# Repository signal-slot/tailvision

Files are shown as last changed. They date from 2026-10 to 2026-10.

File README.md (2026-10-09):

# tailvision

Eyes and a finger for AI agents on a device's physical screen.

> **Status (2026-10-07):** work in progress. Builds, unit tests and the SD
> image pipeline work; nothing has been verified on real hardware yet
> (camera capture, screen detection on real frames, USB gadget, hotspot).

A Raspberry Pi Zero W with a camera module points at the LCD of a board under
development, and plugs into that board's USB port as a touch screen, a
keyboard and a network adapter. An AI agent (Claude Code, or anything that
speaks MCP) calls `take_screenshot` and sees what is really on the panel:
rendering glitches, colours, fonts, the state right after boot, things a
host-side screenshot cannot show. Then it calls `tap` and presses what it saw.
Think of a NanoKVM for devices that have no HDMI output: the video comes
through a camera, the input through USB.

[日本語版 README](README.ja.md)

```
AI agent ──(Tailscale / HTTP)──▶ Pi Zero W: tailvision ──(CSI)──▶ camera module ──▶ target's LCD
                                       │     └──(USB, one cable)──▶ target: touch + keyboard + power
phone / PC ──(Wi-Fi or setup hotspot)──▶ setup page http://tailvision-xxxx.local/
```

## What you get

- One static Rust binary. No Python, no OpenCV, no C libraries.
- MCP over Streamable HTTP at `/mcp`, with a bearer token that exists from the
  first boot. The camera is never open to the network.
- A setup page at `/` for Wi-Fi, hostname and Tailscale, open from the
  hotspot and from the tailnet without any password.
  When the unit cannot find a network it raises its own WPA2 hotspot so the
  page can be reached from a phone.
- Tailscale built in, so the unit is reachable by name from anywhere.
- The board's green LED shows the state at a glance.

## MCP tools

| Tool | Returns | Notes |
| --- | --- | --- |
| `take_screenshot` | image | The LCD only, found in the frame and perspective-corrected, as JPEG |
| `capture_debug` | image | The raw frame with the detected outline drawn on (big dot = top-left) |
| `tap` | text | Touch a point, in pixels of the last `take_screenshot` image |
| `swipe` | text | Drag between two points of the last screenshot |
| `type_text` | text | Type ASCII text on the USB keyboard |
| `calibrate_camera`| image | Measure focus/exposure/white balance once and lock them (`lock=false` to undo) |
| `press_key` | text | One key with modifiers, e.g. `enter`, `ctrl`+`c`, `f5` |
| `list_formats` | text | Pixel formats and frame sizes a UVC camera offers |

`take_screenshot` finds the screen on every call (the camera need not be
fixed). Parameters: `raw=true` returns the whole camera frame;
`reuse_detection=true` keeps the previous corners (faster on a fixed rig);
`manual_corners=[[x,y],...]` overrides detection; `output_width`/`output_height`,
`margin_ratio`, `rotation_degrees` (multiples of 90), `flip_horizontal`,
`flip_vertical`, `min_area_ratio`; and the capture controls `width`/`height`,
`skip_frames`, `quality`.

The image comes out the way the camera sees it. The camera may be held at any
angle and may move between calls, and the unit never guesses which way is up:
there is no stored orientation. The agent looks at the picture and, if the
text reads sideways or upside down, calls again with `rotation_degrees`. Tap
and swipe coordinates always refer to the image the agent received, whichever
rotation it had, so that stays consistent.

Detection looks for the LCD-likeliest convex quadrilateral: candidates from
straight edges, bright/dark masks and the extent of bright UI content, scored
by aspect ratio, size, how much of the content they contain and whether a real
brightness step runs along their border. A dark panel on a dark surface with
no visible bezel is the hard case; there the result is the extent of what is
drawn on the screen. Check with `capture_debug` and fall back to
`manual_corners` when it gets it wrong.

Touch coordinates are pixels of the image the agent just received, so the
agent can look, decide and tap without knowing anything about the camera. The
unit maps them through the detected corners onto the device's touch screen
(`frame_coords=true` accepts raw-frame pixels instead, as seen in
`capture_debug`). `tap` with `hold_ms=800` is a long press.

Two camera stacks: a CSI camera module through libcamera (`rpicam-still`,
exposure/white balance/autofocus settle for `--csi-settle-ms`, default 1.5 s),
or a UVC webcam through V4L2 (MJPEG passed through with the Huffman tables
inserted, YUYV encoded on the Pi, the first `skip_frames` frames dropped).
`--camera auto` picks the CSI module when libcamera sees one.

## HTTP endpoints

| Path | Purpose |
| --- | --- |
| `/` | Setup page |
| `/screen.jpg` | The detected screen, `?ow=800&reuse=1`, plus the capture controls below |
| `/debug.jpg`  | Raw frame with the detected outline drawn on |
| `/shot.jpg`  | Raw frame, `?w=1280&h=720&skip=10&q=85`, for curl and browsers |
| `/mcp` | MCP (Streamable HTTP) |
| anything else | redirects to `/`. On the hotspot the OS connectivity probes land here too, so joining it pops up the "sign in to network" window on the setup page |

Port 80.

## First boot

1. Flash the image, plug in the camera and power, switch on. The very first
   boot of a Zero W takes about 7 minutes (partition resize, reboot, then a
   slow cloud-init run); later boots take about a minute.
2. On its first start the unit names itself **`tailvision-xxxx`**, `xxxx`
   being the last four hex digits of its Wi-Fi MAC (print them on the label),
   so several units have distinct mDNS, hotspot and Tailscale names. About a
   minute after power-on it raises its own Wi-Fi network
   **`tailvision-xxxx-setup`** (WPA2, password **`tailvision-setup`** unless
   the unit shipped with its own, see below). The LED blinks fast while the
   hotspot is up.
3. Join it from a phone or laptop. The "sign in to network" window that
   phones and laptops show for a network without Internet access opens the
   setup page; if it does not appear, open `http://tailvision-xxxx/`
   (or `http://tailvision-xxxx.local/`, or `http://10.42.0.1/`). Being on the hotspot counts as physical access,
   so the page needs no key there.
4. On the page:
   - **Wi-Fi**: pick a network, enter the password, Join. The Zero W has one
     radio, so the hotspot goes away for about a minute: the unit joins the
     network, checks that it can reach the Internet and asks Tailscale for a
     login link, then the hotspot **comes back** and the result is shown at
     the top of the page: the network works (or why not), the Tailscale link
     to approve, and the access key to note down. Approve the link from any
     device on the Internet, press **Go online**, and the unit switches over
     for good; the LED turns solid once it is on Tailscale. If Tailscale is
     not up two minutes later the hotspot returns with a note. (Alternatively
     move your phone to that network and
     reopen `http://tailvision-xxxx.local/`. If the hotspot is back within two
     minutes the password was wrong.
   - **Hostname**: rename when you run several units. The `.local` name, the
     Tailscale name and the hotspot name all follow.
   - **Tailscale**: "Get a login link" shows a URL to approve the node from any
     device. An auth key works too.
   - **Tailscale, log out**: shown once the unit is logged in. Removes the
     unit from the tailnet so it can be re-provisioned or handed on; after
     that it is reachable only on the hotspot.
   - **Access key**: shown on the page together with the exact `claude mcp add`
     command. "Generate a new key" rotates it.
5. Carried out of Wi-Fi range, the unit raises the hotspot again after 90
   seconds and retries the saved networks every 10 minutes.

### LED (the green ACT LED on the board)

| LED | State |
| --- | --- |
| short blip every 2 s | looking for a network |
| fast blink (0.2 s) | setup hotspot is up |
| slow blink (1 s) | on Wi-Fi, Tailscale not logged in |
| solid | Wi-Fi and Tailscale both up: ready to use |

### Who can do what

Access is decided by the path a request comes in on, never by a password a
person types.

- From the setup hotspot everything is open: whoever has the hotspot's WPA2
  password is standing next to the unit.
- From the tailnet everything is open too: Tailscale has authenticated the
  peer (`tailscale whois`), and the tailnet's ACL decides who reaches the unit
  at all. `claude mcp add` needs no header there.
- From anywhere else (the Wi-Fi the unit joined, for instance) the setup page
  is refused, and `/mcp` and the `.jpg` endpoints need
  `Authorization: Bearer <key>` (`?key=` also works for the images). The key
  exists from the first start and is shown on the setup page for copying into
  an agent's configuration; it is for agents, not for people.
- Units can ship with their own hotspot password: write it to
  `hotspot-password` on the boot (FAT) partition and print it on the label.

### When a unit never shows up

Put its card into any PC and read `tailvision-status.txt` on the boot (FAT)
partition: Wi-Fi state, hotspot, Tailscale state and the last error, rewritten
whenever something changes. The systemd journal on the root partition is
persistent too (`journalctl -D <mount>/var/log/journal -u tailvision`).

Files on the boot partition that the unit reads:

| File | Purpose |
| --- | --- |
| `wifi-country` | ISO 3166-1 alpha-2 code; needed before Wi-Fi may transmit |
| `hotspot-password` | per-unit WPA2 password for the setup hotspot |
| `tailscale-authkey`  | joins the tailnet on boot, then the file is deleted |

## Registering with Claude Code

Copy the command shown on the setup page:

```bash
claude mcp add --transport http tailvision http://tailvision/mcp \
  --header "Authorization: Bearer <key>"
```

or in `.mcp.json`:

```json
{
  "mcpServers": {
    "tailvision": {
      "type": "http",
      "url": "http://tailvision/mcp",
      "headers": { "Authorization": "Bearer <key>" }
    }
  }
}
```

`tailvision` resolves through Tailscale MagicDNS from anywhere, and
`tailvision-xxxx.local` through mDNS on the same LAN.

## Hardware

- Raspberry Pi Zero W (or Zero 2 W). Pi OS Lite 32-bit, Trixie or later.
- Raspberry Pi Camera Module 3 (autofocus, good for 10–20 cm) or Module 2 /
  OV5647 (fixed focus), with the 22-pin Zero camera ribbon cable.
- A micro-B to USB-A cable from the port marked **USB** to the device under
  test. That one cable carries power, touch and keyboard.
  To keep the unit alive while the target is power-cycled, feed **PWR IN**
  from a separate supply and put a Schottky diode in the VBUS line of the
  target cable so the unit does not back-feed 5 V into it.
- An 8 GB or larger microSD card.
- A document-camera style arm or mount that keeps the camera over the panel.
  [case/](case/) has a printable case for that.

With a UVC webcam instead: plug it into the **USB** port through an OTG
cable, power the unit from **PWR IN**, and delete the
`dtoverlay=dwc2,dr_mode=peripheral` line from `config.txt` (the port is then
a host and touch/keyboard are unavailable).

### What the device under test sees

A composite USB device: a single-touch digitizer (absolute, 0..32767 on
both axes, mapped by the target to its own display) and a boot-protocol
keyboard. Nothing else by default: the unit is not a network adapter for the
target, and there is no network path between the two. Linux, Android, macOS,
Windows and most RTOS USB stacks need no driver for either.

For debugging, a CDC ECM network adapter can be added: create the file
`usb-ethernet` on the boot partition (`USB_ETHERNET=1` in `image.env` does
that), or run with `--usb-ethernet`. The unit then hands the target an
address on 10.42.1.0/24 and NATs it to its Wi-Fi, so the unit can reach the
target (SSH, ADB) at the address the target picked. Delete the file to turn it
off. Windows would need an RNDIS variant (not built).

## Building

Cross-compiles from Linux x86_64 to a static ARMv6 musl binary using the
`rust-lld` shipped with the toolchain; no cross GCC needed.

```bash
rustup target add arm-unknown-linux-musleabihf
cargo build --release --target arm-unknown-linux-musleabihf
# -> target/arm-unknown-linux-musleabihf/release/tailvision
cargo test                                   # no camera needed
```

To run on the development machine:
`cargo run -- --bind 127.0.0.1:8080 --state-dir ./state --no-hotspot --no-led`.

## Making the SD card image

```bash
deploy/build-image.sh            # -> build/tailvision.img, about a minute
```

The script downloads the official Raspberry Pi OS Lite image (32-bit, Trixie)
and the Tailscale static binary into `build/`, loop-mounts the image (needs
sudo), installs the binary and the services, and writes cloud-init files for
the hostname and user. It asks for a Wi-Fi network (Enter to skip and rely on
the hotspot) and a Tailscale auth key (optional). Nothing else is baked in by
default, so the image can be handed to someone else; `deploy/image.env.example`
lists what can be added (your SSH key, a per-unit hotspot password, ...).

No sshd runs on LAN unless the builder put an SSH key in
`image.env` (development units); password login over SSH is never enabled.
Maintenance access on a plain unit is Tailscale SSH, which the tailnet's ACL
controls, and the setup page.

Flash with Raspberry Pi Imager ("Use custom", answer No to OS customisation) or:

```bash
sudo dd if=build/tailvision.img of=/dev/sdX bs=4M status=progress conv=fsync
```

The first boot takes two to three minutes.

To install on an existing Raspberry Pi OS instead:

```bash
deploy/install.sh pi@tailvision    # binary + systemd units; install Tailscale separately
```

If the card sits in a [microsd-ota](https://github.com/signal-slot/microsd-ota)
bridge, `deploy/update-via-bridge.sh` copies just the binary and units onto
the card over USB while the Pi is powered off, which is far quicker than
re-flashing a rebuilt image (every rebuild changes the ext4 layout, so even a
delta flash moves hundreds of megabytes).

## Options

```
tailvision [--bind [::]:80] [--camera auto|csi|uvc] [--csi-settle-ms 1500]
           [--csi-args "--hflip"] [--no-gadget] [--device /dev/video0]
           [--width W --height H] [--skip-frames 10] [--quality 85]
           [--frame-timeout 5] [--state-dir /var/lib/tailvision]
           [--wifi-iface wlan0] [--hotspot-after 60] [--hotspot-retry 600]
           [--hotspot-password ...] [--hotspot-password-file /boot/firmware/hotspot-password]
           [--no-hotspot] [--led /sys/class/leds/ACT] [--no-led]
```

`RUST_LOG=debug` for more logging.

## Wi-Fi notes

- The hotspot is WPA2 with plain PSK on purpose. With NetworkManager 1.52
  the access point would also offer PSK-SHA256 in the handshake, but the
  Zero W's Wi-Fi firmware writes its own beacon and only advertises PSK;
  every client then rejects the handshake (phones say "wrong password").
  tailvision pins the running access point to WPA-PSK right after it starts.
- The Zero W is 2.4 GHz only. A network that is 5 GHz only is invisible to it.

## Pointing a camera at an LCD

- Framing: every screenshot reports how much of the frame the screen fills.
  With the Camera Module 3 (66° horizontal) a 7-inch panel fills the frame at
  about 12 cm, a 5-inch one at about 9 cm; 30-70% fill is plenty, the
  detector crops the rest.
- Focus, exposure, white balance: calibrate once (see above) rather than
  fighting the automatics on every shot. A shutter time longer than the
  backlight's PWM period (10 ms or more) also removes the flicker bands.
- Moiré: tilt the camera a few degrees or change the capture size.
- Flicker from backlight PWM: lock the exposure, e.g.
  `v4l2-ctl -c exposure_auto=1 -c exposure_absolute=...`.
- Reflections: shade the panel and the camera from room lights.

## Limitations

- Colour is not calibrated: what the camera sees is what you get.
- Tailscale login needs a network with internet access.
- The hotspot password is fixed per unit and printed on it (or the default in
  this README), so it protects against passers-by, not against someone who
  holds the unit.

## License

MIT. Copyright (c) 2026 Signal Slot Inc.

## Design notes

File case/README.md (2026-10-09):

# Case

A printed case for the unit: Raspberry Pi Zero W (or Zero 2 W) with Camera
Module 3. It is meant to hang lens-down over a panel like a document camera,
held by whatever cheap arm is at hand: the back and the ends are flat so a
phone-holder clamp can grip it lengthwise or a rubber band can hold it. The
only openings are the USB port that powers the unit and the microSD slot.

`case.py` is the model (parameters at the top), `stl/` the printed parts,
`preview.png` a render. Dimensions come from the official Zero and Camera
Module 3 drawings; the script also checks that a mock Pi and camera clear
the walls, tubes and bosses.

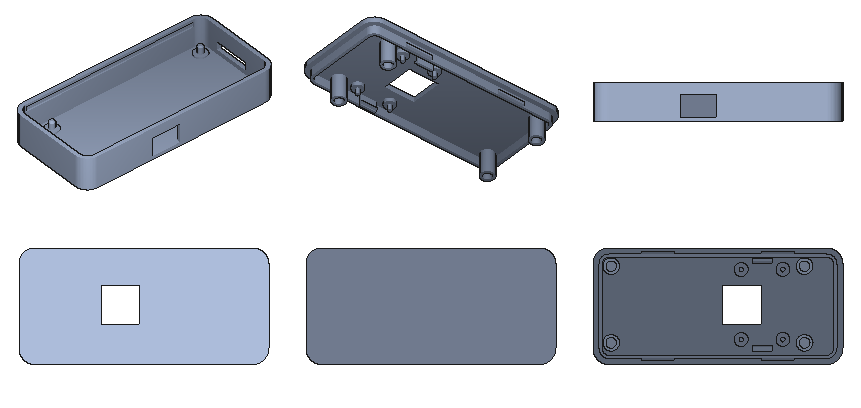
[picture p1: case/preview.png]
preview


## Parts

| | |
|---|---|
| `stl/body.stl` | Pi on four pegs rising from the floor, openings for the USB port and the microSD, a 6 mm pocket at the camera end where the cable U-turns, flat back |
| `stl/lid.stl` | carries the camera lens-out on four pegs and two clips; snaps into the body, and four posts hold the Pi down on the body's pegs |

No screws. Besides the Pi and the camera:

- Raspberry Pi Zero camera cable, 38 mm (the short one sold for the Zero case).

Outer size 75 × 35 × 13.7 mm. The lens housing stands 0.7 mm proud of the lid and the lens tip 4.3 mm, so do not lay the unit lens down on a hard desk. The bottom is flat and closed.

## Printing

No supports. PLA or PETG, 0.2 mm layers, 3 walls. The snap ridges, the camera clips and the pegs are small: 0.4 mm nozzle, no "elephant foot" compensation on the lid's lip.

- `body.stl` open side up, as exported.
- `lid.stl` outer face down, as exported; the four 8.3 mm posts and the clips print upward.

## Assembly

1. Press the Pi onto the four pegs, USB port at the opening, microSD slot at the end wall (the card goes in and out through it). Mini HDMI and PWR IN are closed. The camera connector end faces the pocket.
2. Press the camera onto the lid's four pegs, lens through the window, connector edge toward the pocket end of the lid, until the two clips snap over its long edges.
3. Plug the 38 mm cable into the Pi (contacts toward the board), fold it up and back over the Pi edge, plug it into the camera (contacts toward the camera board).
4. Lower the lid, lip inside the walls, and press the long sides until the ridges click into the wall grooves. The posts land on the Pi around its holes. To open, pry a long side up at an end.

## Mounting with cheap parts

- A clip-on flexible-arm phone holder (100-yen shops sell them for a few hundred yen): clamp the base to the desk or shelf and let the phone clamp grip the case end to end (75 mm, within the usual 55–85 mm range).
- A tall wire book stand: lash the case to the top with a rubber band, panel at the bottom.

## Changing the model

```
uv venv .venv && . .venv/bin/activate
uv pip install manifold3d numpy pillow
python3 case.py                      # stl/*.stl, preview.png
python3 case.py --copy-to ~/shared   # and a fresh copy of each STL there
```

Everything is a named constant at the top of `case.py`: wall thickness, clearance, where the camera sits (`CAM_BOTTOM_X`), the port opening. The checks print a line per overlap when a change collides with the Pi or the camera.

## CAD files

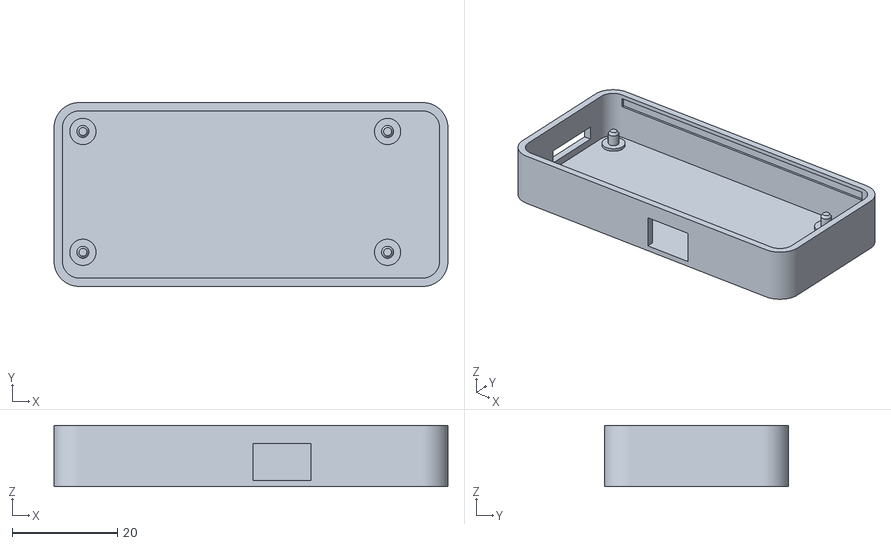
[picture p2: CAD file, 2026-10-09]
case/stl/body.stl
75.0 x 35.0 x 11.7

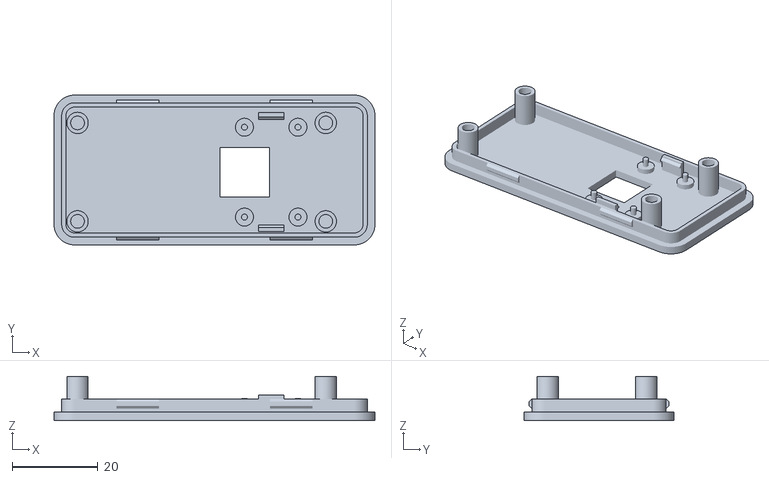
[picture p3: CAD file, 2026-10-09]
case/stl/lid.stl
75.0 x 35.0 x 10.3

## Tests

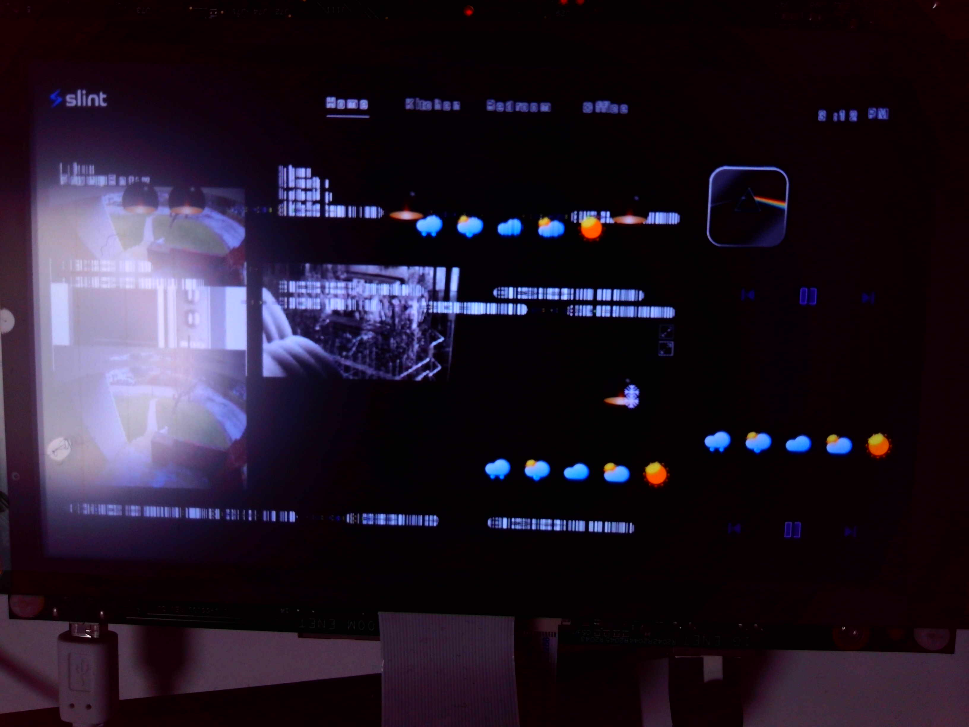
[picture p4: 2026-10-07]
tests/fixtures/scene01_dark_ui_slint.png

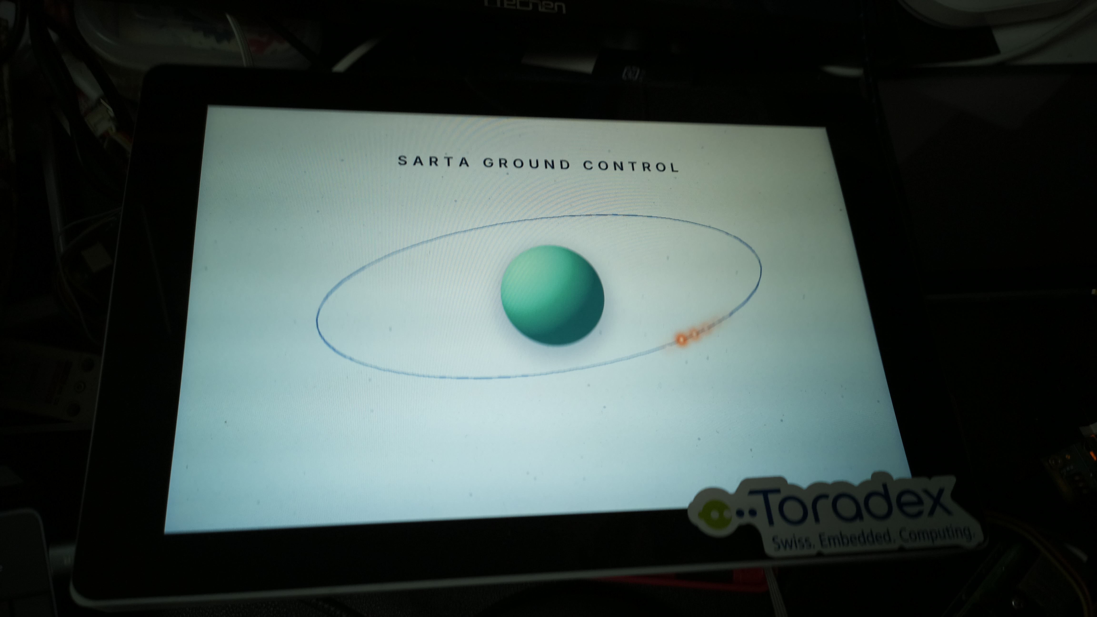
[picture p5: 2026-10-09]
tests/fixtures/scene03_bright_tablet_bezel.png

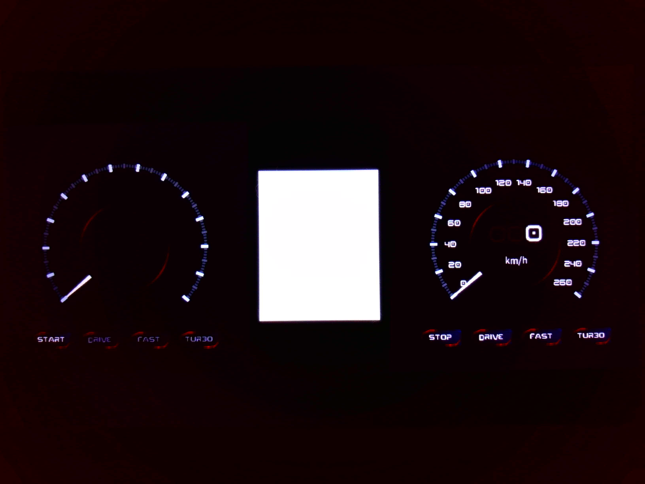
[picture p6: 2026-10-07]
tests/fixtures/scene02_dashboard_dark.png

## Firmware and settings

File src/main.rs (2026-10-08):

//! tailvision: an MCP server that photographs whatever a USB webcam is pointed at.
//!
//! Runs on the machine the camera is plugged into (a Raspberry Pi Zero W, say)
//! and speaks MCP over Streamable HTTP at `/mcp`. A plain `GET /shot.jpg` is
//! served for browsers and curl, and `/` is a setup page for Wi-Fi, hostname,
//! Tailscale and the access key. When no network is reachable the device
//! raises an open `<hostname>-setup` hotspot so the setup page can be reached.

mod capture;
mod config;
mod gadget;
mod led;
mod libcamera;
mod mjpeg;
mod netmgr;
mod pipeline;
mod screen;
mod supervisor;
mod tailscale;
mod touch;
mod v4l2;
mod web;

use std::collections::HashMap;
use std::path::PathBuf;
use std::sync::Arc;
use std::time::Duration;

use anyhow::Context as _;
use axum::extract::{Query, State};
use axum::http::{StatusCode, header};
use axum::response::{IntoResponse, Response};
use axum::routing::{get, post};
use base64::Engine as _;
use clap::Parser;
use rmcp::handler::server::wrapper::Parameters;
use rmcp::model::{CallToolResult, ContentBlock, ErrorData, ServerCapabilities, ServerConfig};
use rmcp::transport::streamable_http_server::session::local::LocalSessionManager;
use rmcp::transport::{StreamableHttpServerConfig, StreamableHttpService};
use rmcp::{ServerHandler, tool, tool_handler, tool_router};
use tokio::sync::{Mutex, RwLock};

use capture::{Shot, ShotRequest};

/// Default hostname, and therefore the default `.local` name, Tailscale name
/// and setup hotspot name (`<hostname>-setup`).
pub const PRODUCT_NAME: &str = "tailvision";
/// Used when no --hotspot-password and no password file is present.
pub const DEFAULT_HOTSPOT_PASSWORD: &str = "tailvision-setup";

#[derive(Parser, Debug, Clone)]
#[command(
    version,
    about = "tailvision: a camera-based KVM for AI agents, served over MCP"
)]
pub struct Cli {
    /// Address to listen on.
    #[arg(long, default_value = "[::]:80")]
    bind: String,
    /// V4L2 device node.
    #[arg(long, default_value = "/dev/video0")]
    pub device: String,
    /// Default capture width (omit both to use the camera's largest size).
    #[arg(long)]
    width: Option<u32>,
    /// Default capture height.
    #[arg(long)]
    height: Option<u32>,
    /// Frames to discard before keeping one, so auto-exposure settles.
    #[arg(long, default_value_t = 10)]
    skip_frames: u32,
    /// JPEG quality for cameras that only deliver raw YUYV.
    #[arg(long, default_value_t = 85)]
    quality: u8,
    /// Seconds to wait for a single frame before giving up.
    #[arg(long, default_value_t = 5)]
    frame_timeout: u64,
    /// Where the access key is stored.
    #[arg(long, default_value = "/var/lib/tailvision")]
    state_dir: PathBuf,
    /// Wi-Fi interface managed by NetworkManager.
    #[arg(long, default_value = "wlan0")]
    pub wifi_iface: String,
    /// Seconds without any network before the setup hotspot is raised.
    #[arg(long, default_value_t = 60)]
    pub hotspot_after: u64,
    /// Seconds between attempts to leave the hotspot for a saved network.
    #[arg(long, default_value_t = 600)]
    pub hotspot_retry: u64,
    /// WPA2 password of the setup hotspot (8+ characters). Overrides --hotspot-password-file.
    #[arg(long)]
    pub hotspot_password: Option<String>,
    /// File holding the hotspot password, so each unit can ship its own (printed on a label).
    #[arg(long, default_value = "/boot/firmware/hotspot-password")]
    pub hotspot_password_file: PathBuf,
    /// Wi-Fi regulatory domain (ISO 3166-1 alpha-2). Overrides --wifi-country-file.
    #[arg(long)]
    pub wifi_country: Option<String>,
    /// File holding the Wi-Fi country code, written by the image builder.
    #[arg(long, default_value = "/boot/firmware/wifi-country")]
    pub wifi_country_file: PathBuf,
    /// Plain-text status written for offline diagnosis (empty disables).
    #[arg(long, default_value = "/boot/firmware/tailvision-status.txt")]
    pub status_file: Option<PathBuf>,
    /// Never raise the setup hotspot (for development machines).
    #[arg(long)]
    pub no_hotspot: bool,
    /// LED sysfs directory for status blinking (default: /sys/class/leds/ACT, then led0).
    #[arg(long)]
    pub led: Option<PathBuf>,
    /// Leave the activity LED alone.
    #[arg(long)]
    pub no_led: bool,
    /// Camera stack: auto (CSI module if libcamera sees one, else UVC), csi, or uvc.
    #[arg(long, default_value = "auto")]
    pub camera: String,
    /// Milliseconds the CSI camera runs before the capture so exposure and focus settle.
    #[arg(long, default_value_t = 1500)]
    pub csi_settle_ms: u64,
    /// Extra rpicam-still arguments, e.g. "--hflip --vflip" or "--shutter 20000".
    #[arg(long, default_value = "")]
    pub csi_args: String,
    /// Do not set up the USB gadget (touch screen, keyboard) even if a UDC exists.
    #[arg(long)]
    pub no_gadget: bool,
    /// Debugging: also expose a USB Ethernet (CDC ECM) link to the device under test,
    /// 10.42.1.0/24 with NAT to Wi-Fi, so the unit can reach the target (SSH, ADB).
    #[arg(long)]
    pub usb_ethernet: bool,
    /// The USB Ethernet link is also enabled while this file exists.
    #[arg(long, default_value = "/boot/firmware/usb-ethernet")]
    pub usb_ethernet_file: PathBuf,
}

#[derive(Clone)]
pub struct App {
    pub cli: Arc<Cli>,
    pub hotspot_password: Arc<String>,
    pub wifi_country: Option<String>,
    pub camera: Camera,
    pub config: Arc<RwLock<config::Config>>,
    pub store: Arc<config::Store>,
    pub net: Arc<supervisor::NetState>,
    pub login: Arc<tailscale::Login>,
    pub corners: Arc<pipeline::CornerCache>,
    pub gadget: Option<Arc<gadget::Gadget>>,
    pub backend: capture::Backend,
}

#[derive(Clone)]
pub struct Camera {
    cli: Arc<Cli>,
    backend: capture::Backend,
    config: Arc<RwLock<config::Config>>,
    store: Arc<config::Store>,
    /// Only one capture at a time: the device cannot be opened twice.
    lock: Arc<Mutex<()>>,
    corners: Arc<pipeline::CornerCache>,
}

impl Camera {
    fn request(
        &self,
        width: Option<u32>,
        height: Option<u32>,
        skip: Option<u32>,
        quality: Option<u8>,
    ) -> ShotRequest {
        ShotRequest {
            backend: match self.backend.clone() {
                capture::Backend::Csi {
                    settle,
                    autofocus,
                    extra_args,
                    ..
                } => capture::Backend::Csi {
                    settle,
                    autofocus,
                    lock: self
                        .config
                        .try_read()
                        .ok()
                        .and_then(|c| c.camera_lock.clone()),
                    extra_args,
                },
                other => other,
            },
            device: self.cli.device.clone(),
            width: width.or(self.cli.width),
            height: height.or(self.cli.height),
            skip_frames: skip.unwrap_or(self.cli.skip_frames),
            quality: quality.unwrap_or(self.cli.quality),
            frame_timeout: Duration::from_secs(self.cli.frame_timeout),
        }
    }

    async fn shoot(&self, req: ShotRequest) -> anyhow::Result<Shot> {
        let _guard = self.lock.lock().await;
        tokio::task::spawn_blocking(move || capture::take_shot(&req))
            .await
            .context("capture task")?
    }

    fn screen_request(&self, p: &ShotParams) -> anyhow::Result<pipeline::ScreenRequest> {
        let manual_corners = match &p.manual_corners {
            None => None,
            Some(v) if v.len() == 4 => Some([
                (v[0][0], v[0][1]),
                (v[1][0], v[1][1]),
                (v[2][0], v[2][1]),
                (v[3][0], v[3][1]),
            ]),
            Some(_) => anyhow::bail!("manual_corners needs exactly four [x, y] points"),
        };
        Ok(pipeline::ScreenRequest {
            shot: self.request(p.width, p.height, p.skip_frames, p.quality),
            options: screen::Options {
                min_area_ratio: p.min_area_ratio.unwrap_or(0.05).clamp(0.0, 1.0),
                output_width: p.output_width,
                output_height: p.output_height,
                margin_ratio: p.margin_ratio.unwrap_or(0.0).clamp(-0.5, 0.5),
                rotation_degrees: p.rotation_degrees.unwrap_or(0),
                flip_horizontal: p.flip_horizontal.unwrap_or(false),
                flip_vertical: p.flip_vertical.unwrap_or(false),
            },
            manual_corners,
            reuse_detection: p.reuse_detection.unwrap_or(false),
            jpeg_quality: p.quality.unwrap_or(self.cli.quality),
        })
    }

    async fn screen(
        &self,
        req: pipeline::ScreenRequest,
        debug: bool,
    ) -> anyhow::Result<pipeline::ScreenShot> {
        let _guard = self.lock.lock().await;
        let cache = self.corners.clone();
        tokio::task::spawn_blocking(move || {
            if debug {
                pipeline::take_debug(&req, &cache)
            } else {
                pipeline::take_screen(&req, &cache)
            }
        })
        .await
        .context("capture task")?
    }

    /// Measures focus / exposure / white balance on the CSI camera and stores
    /// them as the lock for all later captures. Returns the lock and a preview.
    pub async fn calibrate(&self) -> anyhow::Result<(libcamera::CameraLock, Vec<u8>)> {
        let _guard = self.lock.lock().await;
        let capture::Backend::Csi {
            settle,
            autofocus,
            extra_args,
            ..
        } = self.backend.clone()
        else {
            anyhow::bail!(
                "calibration needs the CSI camera (a UVC webcam keeps its own automatic settings)"
            );
        };
        let req = libcamera::CsiRequest {
            width: self.cli.width,
            height: self.cli.height,
            settle,
            quality: self.cli.quality,
            autofocus,
            lock: None,
            extra_args,
        };
        let (lock, jpeg) = tokio::task::spawn_blocking(move || libcamera::calibrate(&req))
            .await
            .context("calibration task")??;
        let mut cfg = self.config.read().await.clone();
        cfg.camera_lock = Some(lock.clone());
        self.store.save(&cfg)?;
        *self.config.write().await = cfg;
        Ok((lock, jpeg))
    }

    pub async fn unlock(&self) -> anyhow::Result<()> {
        let mut cfg = self.config.read().await.clone();
        cfg.camera_lock = None;
        self.store.save(&cfg)?;
        *self.config.write().await = cfg;
        Ok(())
    }

    async fn formats(&self) -> anyhow::Result<Vec<capture::FormatInfo>> {
        let _guard = self.lock.lock().await;
        let device = self.cli.device.clone();
        tokio::task::spawn_blocking(move || capture::list_formats(&device))
            .await
            .context("format task")?
    }
}

#[derive(Debug, serde::Deserialize, schemars::JsonSchema, Default)]
struct ShotParams {
    /// Return the raw camera frame instead of the detected screen (default false).
    raw: Option<bool>,
    /// Reuse the corners from the previous detection instead of detecting again (default false; faster when the camera does not move).
    reuse_detection: Option<bool>,
    /// Four [x, y] points in raw-frame pixels, any order, overriding detection.
    manual_corners: Option<Vec<[f32; 2]>>,
    /// Width of the rectified screen image; defaults to the detected size.
    output_width: Option<u32>,
    /// Height of the rectified screen image; defaults to the detected size.
    output_height: Option<u32>,
    /// Shrink (positive) or grow (negative) the detected quad toward its centre, as a fraction (-0.5..0.5).
    margin_ratio: Option<f32>,
    /// Rotate the result by 0, 90, 180 or 270 degrees (default 0: the image comes out the way the camera sees it).
    rotation_degrees: Option<i32>,
    /// Mirror the result left-right (default false).
    flip_horizontal: Option<bool>,
    /// Mirror the result top-bottom (default false).
    flip_vertical: Option<bool>,
    /// Smallest candidate area as a fraction of the frame (default 0.05).
    min_area_ratio: Option<f32>,
    /// Camera capture width; must be given together with height. Defaults to the camera's largest size.
    width: Option<u32>,
    /// Camera capture height.
    height: Option<u32>,
    /// Frames to discard before keeping one, so auto-exposure can settle (default 10).
    skip_frames: Option<u32>,
    /// JPEG quality 1-100 of the returned image (default 85).
    quality: Option<u8>,
}

fn csi_backend(cli: &Cli, info: Option<&libcamera::CameraInfo>) -> capture::Backend {
    capture::Backend::Csi {
        settle: Duration::from_millis(cli.csi_settle_ms),
        autofocus: info.is_some_and(|i| i.autofocus),
        lock: None, // filled per request from the saved calibration
        extra_args: cli.csi_args.split_whitespace().map(String::from).collect(),
    }
}

#[derive(Clone)]
struct TailvisionServer {
    camera: Camera,
    gadget: Option<Arc<gadget::Gadget>>,
}

#[derive(Debug, serde::Deserialize, schemars::JsonSchema, Default)]
struct CalibrateParams {
    /// true (default): measure and lock; false: clear the lock and return to automatic.
    lock: Option<bool>,
}

#[derive(Debug, serde::Deserialize, schemars::JsonSchema, Default)]
struct TapParams {
    /// X in pixels of the last take_screenshot image (or of the raw frame when frame_coords is true).
    x: f32,
    /// Y in pixels of the last take_screenshot image.
    y: f32,
    /// Interpret x/y as raw camera-frame pixels (as in capture_debug) instead of screenshot pixels.
    frame_coords: Option<bool>,
    /// How long the finger stays down, in ms (default 60; use 800+ for a long press).
    hold_ms: Option<u64>,
}

#[derive(Debug, serde::Deserialize, schemars::JsonSchema, Default)]
struct SwipeParams {
    /// Start X in pixels of the last take_screenshot image.
    x1: f32,
    y1: f32,
    /// End X in pixels of the last take_screenshot image.
    x2: f32,
    y2: f32,
    /// Interpret the points as raw camera-frame pixels instead of screenshot pixels.
    frame_coords: Option<bool>,
    /// Duration of the gesture in ms (default 300).
    duration_ms: Option<u64>,
}

#[derive(Debug, serde::Deserialize, schemars::JsonSchema, Default)]
struct TextParams {
    /// Printable ASCII text; "\n" presses Enter, "\t" presses Tab. Other characters are skipped.
    text: String,
}

#[derive(Debug, serde::Deserialize, schemars::JsonSchema, Default)]
struct KeyParams {
    /// Key name: a single character, or enter, esc, tab, backspace, space, up, down, left, right, home, end, pageup, pagedown, delete, f1..f12.
    key: String,
    /// Modifiers joined with "+", e.g. "ctrl", "ctrl+shift", "alt", "gui".
    modifiers: Option<String>,
}

fn tool_error(e: anyhow::Error) -> ErrorData {
    ErrorData::internal_error(format!("{e:#}"), None)
}

fn image_result(jpeg: &[u8], note: String) -> CallToolResult {
    let b64 = base64::engine::general_purpose::STANDARD.encode(jpeg);
    CallToolResult::success(vec![
        ContentBlock::image(b64, "image/jpeg"),
        ContentBlock::text(note),
    ])
}
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
async fn main() -> anyhow::Result<()> {
    tracing_subscriber::fmt()
        .with_env_filter(
            tracing_subscriber::EnvFilter::try_from_default_env().unwrap_or_else(|_| "info".into()),
        )
        .init();

    let cli = Arc::new(Cli::parse());
    let store = config::Store::new(&cli.state_dir);
    let mut config = store
        .load()
        .with_context(|| format!("load settings from {}", cli.state_dir.display()))?;
    // The MCP endpoint and the camera are never open: mint a key on first start.
    if config.mcp_key.is_none() {
        config.mcp_key = Some(config::generate_key()?);
        store
            .save(&config)
            .context("store the generated access key")?;
        tracing::info!("generated a new access key; read it on the setup page");
    }
    let hotspot_password = match &cli.hotspot_password {
        Some(p) => p.clone(),
        None => std::fs::read_to_string(&cli.hotspot_password_file)
            .map(|s| s.trim().to_string())
            .unwrap_or_else(|_| DEFAULT_HOTSPOT_PASSWORD.to_string()),
    };
    if !hotspot_password.is_empty() && hotspot_password.len() < 8 {
        anyhow::bail!("hotspot password must be at least 8 characters");
    }
    let wifi_country = cli.wifi_country.clone().or_else(|| {
        std::fs::read_to_string(&cli.wifi_country_file)
            .ok()
            .map(|s| s.trim().to_uppercase())
            .filter(|s| s.len() == 2)
    });
    let corners = Arc::new(pipeline::CornerCache::default());
    let config_shared = Arc::new(RwLock::new(config));
    let store_shared = Arc::new(store);
    let csi = libcamera::probe();
    let backend = match (cli.camera.as_str(), &csi) {
        ("uvc", _) => capture::Backend::V4l2,
        ("csi", _) | ("auto", Some(_)) => csi_backend(&cli, csi.as_ref()),
        _ => capture::Backend::V4l2,
    };
    if let Some(info) = &csi {
        tracing::info!(model = %info.model, autofocus = info.autofocus, "CSI camera");
    }
    tracing::info!(backend = ?backend, "camera");
    let hostname = std::fs::read_to_string("/etc/hostname")
        .map(|s| s.trim().to_string())
        .unwrap_or_else(|_| PRODUCT_NAME.into());
    let usb_ethernet = cli.usb_ethernet || cli.usb_ethernet_file.exists();
    let gadget = if cli.no_gadget {
        None
    } else {
        match gadget::Gadget::setup(PRODUCT_NAME, &hostname, usb_ethernet) {
            Ok(Some(g)) => Some(Arc::new(g)),
            Ok(None) => {
                tracing::info!(
                    "no USB device controller: gadget mode off (touch/keyboard unavailable)"
                );
                None
            }
            Err(e) => {
                tracing::warn!(error = %format!("{e:#}"), "USB gadget setup failed");
                None
            }
        }
    };
    let app = App {
        hotspot_password: Arc::new(hotspot_password),
        wifi_country,
        camera: Camera {
            cli: cli.clone(),
            backend: backend.clone(),
            config: config_shared.clone(),
            store: store_shared.clone(),
            lock: Arc::new(Mutex::new(())),
            corners: corners.clone(),
        },
        cli: cli.clone(),
        config: config_shared.clone(),
        store: store_shared.clone(),
        net: Arc::new(supervisor::NetState::default()),
        login: Arc::new(tailscale::Login::default()),
        corners,
        gadget: gadget.clone(),
        backend,
    };
    if let Ok(h) = netmgr::hostname().await {
        netmgr::write_local_dns(&h);
    }
    if gadget.is_some() && usb_ethernet {
        tracing::info!("debugging USB Ethernet link enabled");
        tokio::spawn(netmgr::ensure_usb_ethernet());
    }

    // The server is reached through Tailscale, mDNS or the hotspot by whatever
    // name the client likes, so Host-header allow-listing would only get in the way.
    let mcp_config = StreamableHttpServerConfig::default().disable_allowed_hosts();
    let mcp = StreamableHttpService::new(
        {
            let camera = app.camera.clone();
            let gadget = app.gadget.clone();
            move || Ok(TailvisionServer::new(camera.clone(), gadget.clone()))
        },
        Arc::new(LocalSessionManager::default()),
        mcp_config,
    );

    let router = axum::Router::new()
        .route("/", get(web::index))
        .route("/shot.jpg", get(shot_jpg))
        .route("/screen.jpg", get(screen_jpg))
        .route("/debug.jpg", get(debug_jpg))
        .route("/api/state", get(web::api_state))
        .route("/api/wifi/join", post(web::wifi))
        .route("/api/wifi/forget", post(web::forget))
        .route("/api/wifi/rescan", post(web::rescan))
        .route("/api/go-online", post(web::go_online))
        .route("/api/cancel", post(web::cancel))
        .route("/api/hostname", post(web::hostname))
        .route("/api/tailscale/key", post(web::tailscale_key))
        .route("/api/tailscale/login", post(web::tailscale_login))
        .route("/api/tailscale/logout", post(web::tailscale_logout))
        .route("/api/key/generate", post(web::key_generate))
        .nest_service("/mcp", mcp)
        .fallback(web::fallback)
        .layer(axum::middleware::from_fn_with_state(
            app.clone(),
            web::require_key,
        ))
        .with_state(app.clone());

    tokio::spawn(supervisor::run(app.clone()));

    let listener = tokio::net::TcpListener::bind(&cli.bind)
        .await
        .with_context(|| format!("bind {}", cli.bind))?;
    tracing::info!(bind = %cli.bind, device = %cli.device, state = %cli.state_dir.display(), "listening");
    axum::serve(
        listener,
        router.into_make_service_with_connect_info::<std::net::SocketAddr>(),
    )
    .with_graceful_shutdown(async {
        let _ = tokio::signal::ctrl_c().await;
    })
    .await?;
    Ok(())
}

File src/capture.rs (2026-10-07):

//! Single-frame capture from a V4L2 (UVC) camera, returned as a JPEG.
//!
//! MJPEG cameras hand us a JPEG directly (after a DHT fix-up); YUYV cameras
//! are encoded here with `jpeg-encoder`. Everything is blocking and meant to
//! be run on a blocking thread.

use std::fmt;
use std::io;
use std::time::Duration;

use anyhow::{Context, Result, anyhow, bail};

use crate::mjpeg;
use crate::v4l2::{Device, FourCC};

pub const MJPG: FourCC = FourCC(*b"MJPG");
pub const YUYV: FourCC = FourCC(*b"YUYV");
/// Marker for frames that came from libcamera rather than V4L2.
pub const CSI: FourCC = FourCC(*b"CSI ");

/// Which camera stack grabs the frame.
#[derive(Debug, Clone, Default)]
pub enum Backend {
    /// UVC webcam through V4L2 (`device`).
    #[default]
    V4l2,
    /// CSI camera module through libcamera (`rpicam-still`).
    Csi {
        settle: Duration,
        autofocus: bool,
        lock: Option<crate::libcamera::CameraLock>,
        extra_args: Vec<String>,
    },
}

#[derive(Debug, Clone, Default)]
pub struct ShotRequest {
    pub backend: Backend,
    pub device: String,
    /// Desired size; `None` picks the largest the camera offers.
    pub width: Option<u32>,
    pub height: Option<u32>,
    /// Frames to discard before keeping one, so auto-exposure can settle.
    pub skip_frames: u32,
    /// JPEG quality used only when the camera delivers raw YUYV.
    pub quality: u8,
    /// Give up if the camera does not deliver a frame in this time.
    pub frame_timeout: Duration,
}

#[derive(Debug, Clone)]
pub struct Shot {
    pub jpeg: Vec<u8>,
    pub width: u32,
    pub height: u32,
    pub fourcc: FourCC,
    pub frames_skipped: u32,
}

#[derive(Debug, Clone)]
pub struct FormatInfo {
    pub fourcc: FourCC,
    pub description: String,
    pub sizes: Vec<(u32, u32)>,
}

impl fmt::Display for FormatInfo {
    fn fmt(&self, f: &mut fmt::Formatter<'_>) -> fmt::Result {
        write!(f, "{} ({})", self.fourcc, self.description)?;
        for (w, h) in &self.sizes {
            write!(f, "\n  {w}x{h}")?;
        }
        Ok(())
    }
}

/// Lists every pixel format and discrete frame size the device offers.
pub fn list_formats(device: &str) -> Result<Vec<FormatInfo>> {
    let dev = Device::open(device).with_context(|| format!("open {device}"))?;
    formats_of(&dev)
}

fn formats_of(dev: &Device) -> Result<Vec<FormatInfo>> {
    let mut out = Vec::new();
    for desc in dev.enum_formats().context("enumerate formats")? {
        let mut sizes = dev.enum_framesizes(desc.fourcc).unwrap_or_default();
        sizes.sort_unstable();
        sizes.dedup();
        out.push(FormatInfo {
            fourcc: desc.fourcc,
            description: desc.description,
            sizes,
        });
    }
    Ok(out)
}

/// Picks the frame size: exact match if offered, otherwise the largest size
/// that fits inside the request, otherwise the largest size at all.
fn choose_size(sizes: &[(u32, u32)], want: Option<(u32, u32)>) -> Option<(u32, u32)> {
    let largest =
        |it: &mut dyn Iterator<Item = &(u32, u32)>| it.max_by_key(|(w, h)| w * h).copied();
    match want {
        Some(w) if sizes.contains(&w) => Some(w),
        Some((ww, wh)) => largest(&mut sizes.iter().filter(|(w, h)| *w <= ww && *h <= wh))
            .or_else(|| largest(&mut sizes.iter())),
        None => largest(&mut sizes.iter()),
    }
}

/// Grabs one frame and returns it as JPEG.
pub fn take_shot(req: &ShotRequest) -> Result<Shot> {
    if let Backend::Csi {
        settle,
        autofocus,
        lock,
        extra_args,
    } = &req.backend
    {
        let csi = crate::libcamera::CsiRequest {
            width: req.width,
            height: req.height,
            settle: *settle,
            quality: req.quality,
            autofocus: *autofocus,
            lock: lock.clone(),
            extra_args: extra_args.clone(),
        };
        let (jpeg, width, height) = crate::libcamera::take_jpeg(&csi)?;
        return Ok(Shot {
            jpeg,
            width,
            height,
            fourcc: CSI,
            frames_skipped: 0,
        });
    }
    let dev = Device::open(&req.device).with_context(|| format!("open {}", req.device))?;
    let formats = formats_of(&dev)?;
    let chosen = formats
        .iter()
        .find(|f| f.fourcc == MJPG)
        .or_else(|| formats.iter().find(|f| f.fourcc == YUYV))
        .ok_or_else(|| {
            anyhow!(
                "camera offers neither MJPG nor YUYV (has: {})",
                formats
                    .iter()
                    .map(|f| f.fourcc.to_string())
                    .collect::<Vec<_>>()
                    .join(", ")
            )
        })?;
    let want = match (req.width, req.height) {
        (Some(w), Some(h)) => Some((w, h)),
        (None, None) => None,
        _ => bail!("width and height must be given together"),
    };
    let (w, h) =
        choose_size(&chosen.sizes, want).ok_or_else(|| anyhow!("camera reports no frame sizes"))?;

    let actual = dev
        .set_format(w, h, chosen.fourcc)
        .with_context(|| format!("set format {}x{} {}", w, h, chosen.fourcc))?;
    let actual_fourcc = FourCC(actual.pixelformat.to_le_bytes());
    if actual_fourcc != chosen.fourcc {
        bail!("driver changed pixel format to {actual_fourcc}");
    }

    let mut stream = dev.start_stream(4).context("start stream")?;
    let mut frames_skipped = 0;
    let frame = loop {
        let frame = stream
            .next_frame(req.frame_timeout, |data| data.to_vec())
            .map_err(|e| timeout_hint(e, req.frame_timeout))?;
        // UVC drivers occasionally deliver an empty or truncated first buffer; skip those too.
        if frames_skipped >= req.skip_frames && !frame.is_empty() {
            break frame;
        }
        frames_skipped += 1;
    };
    drop(stream);

    let jpeg = if actual_fourcc == MJPG {
        mjpeg::ensure_dht(&frame)
    } else {
        encode_yuyv(
            &frame,
            actual.width,
            actual.height,
            actual.bytesperline,
            req.quality,
        )?
    };

    Ok(Shot {
        jpeg,
        width: actual.width,
        height: actual.height,
        fourcc: actual_fourcc,
        frames_skipped,
    })
}

fn timeout_hint(e: io::Error, timeout: Duration) -> anyhow::Error {
    if e.kind() == io::ErrorKind::TimedOut {
        anyhow!("no frame within {timeout:?}; is the camera busy or unplugged?")
    } else {
        anyhow::Error::from(e).context("dequeue frame")
    }
}
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

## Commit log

2026-10-07 tailvision: camera KVM for AI agents on a Raspberry Pi Zero W
    A camera module looks at the LCD of a device under test and the Pi's USB
    port acts as a touch digitizer and keyboard toward it, all exposed to Claude
    Code over MCP (Streamable HTTP on port 80), reachable through Tailscale.
    - Rust, single static ARMv6 musl binary; own V4L2 ioctl layer for UVC
    webcams, rpicam-still for CSI modules (autofocus on Camera Module 3 and
    other AF sensors).
    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
2026-10-08 Provisioning that works on a Zero W: hotspot round trip, PSK pin, per-unit names
    Verified end to end on hardware through the product path only (a PC joining
    the hotspot like a phone would): fresh unit -> hotspot -> Join on the page ->
    hotspot returns with the result -> approve the Tailscale link -> Go online ->
    unit on the tailnet, page reachable by name with the key shown on the page.
    Wi-Fi on the BCM43430 (Pi OS Trixie, NetworkManager 1.52):
    - The hotspot must disable PMF: the firmware cannot install an IGTK and the
    AP never starts ("key setting validation failed").
    - NM hands the AP key_mgmt "WPA-PSK WPA-PSK-SHA256" while the firmware
    writes its own beacon RSN element with PSK only,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
    [main.rs]
2026-10-08 Captive portal on the hotspot and the USB link
    Joining the setup hotspot now opens the phone's or laptop's "sign in to
    network" window on the setup page, so nobody has to type an address.
    dnsmasq on both shared links answers the names the operating systems probe
    right after joining (connectivitycheck.gstatic.com, captive.apple.com,
    www.msftconnecttest.com, detectportal.firefox.com, ...) with the unit's
    address on that link (localise-queries). Only those names: everything else
    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
2026-10-08 Screenshots come out the way the camera sees them; no stored orientation
    The camera is not fixed: it may be held at any angle and move between
    calls, so a saved default rotation would silently apply a stale guess.
    Drop the setup page's Image section and the rotation/flip fields of
    config.json (old files still load; the fields are ignored). The unit never
    guesses which way is up. take_screenshot says so and tells the agent to
    call again with rotation_degrees when the text reads sideways or upside
    down; tap and swipe coordinates already refer to the image as returned.
    [main.rs]
2026-10-08 USB gadget is touch and keyboard only; the Ethernet link is a debugging option
    The unit must not be a network adapter for the device under test. The CDC
    ECM function, the NetworkManager shared link on usb0 and everything that
    depended on it (setup page without the key from the USB side, name
    resolution and connectivity-probe answers on that link) are gone from the
    default configuration. For debugging the link can still be enabled: a
    `usb-ethernet` marker file on the boot partition (USB_ETHERNET=1 in
    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
2026-10-08 Keep the Tailscale login alive across the hotspot round trip
    `tailscale up` ran with a 10-minute timeout. The unit is back on the
    hotspot, without Internet, while the user approves the link from another
    device, and tailscaled can only pick the approval up after "Go online"; if
    that took longer than ten minutes the login process died, the link vanished
    from the page and every "Go online" came back to the hotspot with
    NeedsLogin. Seen on a unit today.
    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
2026-10-08 Setup page without reloads: static shell, JSON state, JSON actions
    The page is now a static HTML shell (src/setup.html) that polls
    GET /api/state every three seconds and redraws only what changed: Wi-Fi
    state and scan list, saved networks, the Join result, the Tailscale state and
    login link, camera lock, access key. Every button posts JSON to an /api/...
    action and shows the reply in a toast; the state refresh follows. While the
    hotspot is away after Join the page says so and keeps polling, so it catches
    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
2026-10-08 Setup page: drop the Camera section
    Locking focus, exposure and white balance assumes a fixed rig; the camera is
    not fixed, and a stale lock only degrades the next picture. The agent keeps
    calibrate_camera for the cases where it wants that; the page no longer
    offers it.
    [main.rs]
2026-10-09 Printable case for the Zero W + Camera Module 3
    case/case.py models the case with manifold3d from the official Zero and
    Camera Module 3 drawings and writes case/stl/{body,lid}.stl plus a preview.
    Two parts, no screws, no glue: the Pi presses onto four pegs rising from the
    floor and the lid's four posts hold it down; the camera presses onto four
    pegs under the lid and two clips hook over its long edges; the lid snaps
    in with ridges on its lip dropping into grooves in the long walls. The only
    opening is the USB port that powers the unit; the back is flat. 75 x 35 x
    13.7 mm, the height set by the camera's back connector clearing the micro
    USB shells and by the cable's U-turn in the 6 mm pocket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
    [body.stl, lid.stl]
2026-10-09 Screen detection: prefer the edge whose inside looks like the panel
    On a tablet with a sticker on its bezel, the LCD's own edge lost to the
    bezel's outer edge: the sticker made the ring outside the true edge look
    cluttered, while the desk outside the bezel was plain. Add a cue the sticker
    cannot touch: the median of the thin ring just inside a candidate's edge
    against the median of its interior. Inside an LCD's edge is panel like the
    rest; inside the bezel's outer edge is bezel around a panel of another
    brightness. Medians, so a dark UI's bright text does not pass for its
    background (the mean version failed the synthetic dark-UI case).
    The frame is tests/fixtures/scene03_bright_tablet_bezel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
2026-10-09 USB touch: a touchscreen to Linux hosts, and descriptors that update
    The touch report carried an "In Range" bit. Linux maps it to BTN_TOOL_FINGER,
    and udev calls a device with BTN_TOOL_FINGER but no INPUT_PROP_DIRECT a
    touchpad (ID_INPUT_TOUCHPAD): libinput then dropped short taps and turned
    moves into relative motion, so on a Linux host a tap did nothing. Drop the
    usage; with just the tip switch and absolute X/Y the device is a touchscreen
    to udev (ID_INPUT_TOUCHSCREEN), and still to Android and Windows.
    The fix did not take effect on an updated unit: the gadget from the previous
    run stays in configfs, and setup only wrote descriptors for a fresh one. Now
    setup compares each HID function's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
2026-10-09 Case: 0.4 mm between the camera clips and the board edges
    The printed clips at 0.15 mm gripped the camera too hard.
    [lid.stl]
2026-10-09 Case: microSD slot in the end wall
    A seated microSD sticks out about 2 mm past the Zero's board edge, and the
    end wall stood 0.4 mm from it, so with a card in the Pi could not seat on
    its pegs. Open a 13 x 3 mm slot through the end wall at the socket; the card
    goes in and out through it, as in the official case. The clearance checks
    now include the seated card.
    [body.stl]
2026-10-12 MCP: tell the agent how to drive a device
    The server's instructions were three lines. They now walk an agent through
    it: screenshot, act, screenshot again; coordinates are pixels of the last
    screenshot, whatever its size and rotation; the unit never guesses which
    way is up, so rotation_degrees once the text reads wrong; what to do when
    detection is off (dark content, a screen that overflows the frame, a sticker
    on the bezel, reflections) and which knob fixes which (capture_debug,
    min_area_ratio, margin_ratio, manual_corners); that taps land on whatever
    the USB cable is plugged into, scaled to its whole display; that keys go
    through the device's input method, so a Japanese IME in kana mode tu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
2026-10-14 Camera Module 3 Wide: undo the barrel distortion
    A 10-inch panel needs the standard module about 18-25 cm away; the Wide
    (102° horizontal) gets there at about 10-14 cm, but bends the panel's edges,
    and detection (Hough lines, edge refinement) and the perspective warp assume
    straight ones.
    When libcamera reports imx708_wide, a one-parameter division model around
    the frame centre maps camera pixels to a corrected frame of the same size
    that keeps the left and right edge midpoints. Detection runs on the
    corrected small copy; the warp goes from the output through the corrected
    frame to camera pixels in one pass, so no full-size corrected frame is built
    for a screenshot. capture_debug draws on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
2026-10-14 Per-unit hostname follows the board
    The unit named itself tailvision-<last four hex digits of the Wi-Fi MAC>
    once, when its hostname was still the image's "tailvision"; the name then
    lived on the card. Moved to another Zero W, the card kept the old board's
    name for mDNS, Tailscale, the hotspot and the USB serial number.
    At every start a hostname of that form (or plain "tailvision") is now set to
    the current board's digits, and the Tailscale node is renamed with it. Any
    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
2026-10-14 Lens correction follows the part of the sensor a frame shows
    The correction assumed every frame shows the whole sensor. Small output
    sizes can come from a cropped sensor mode: on the IMX708, 1536x864 shows
    only the middle 3072x1728, so a Wide frame at that size was corrected as if
    it bent half again as much as it does.
    rpicam-still now writes its metadata on every capture, and the shot carries
    libcamera's ScalerCrop. The lens profile holds the focal length in sensor
    pixels and the sensor size, and each frame's mapping (optical centre, focal
    length in frame pixels) is built from its size and crop; without a crop the
    frame is taken to show the whole sensor as before. detect and rectify take
    t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
2026-10-14 calibrate_camera measures the Wide's lens from the screen's edges
    λ was an estimate from the datasheet's field of view. The LCD in front of
    the camera has straight edges, so the λ that makes them straight is the
    lens's own (the plumb-line method); no screen dimensions are needed.
    On a wide-angle module calibrate_camera now finds the screen, gathers the
    edge pixels along its four sides (away from the corners, outliers dropped),
    and searches λ for the smallest RMS distance from straight lines, in two
    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
2026-10-15 Case: camera pegs the right way round, lens window in the middle of the lid
    The Camera Module 3 drawing measures the mounting holes (2.0, 14.5) and the
    lens (14.4) from the edge away from the connector. The model counted them
    from the connector edge, so the pegs and the window came out reversed end
    for end against a real camera. Both are now counted from the far edge; the
    lens stays level with one row of holes, as on the drawing.
    The window's position is now the parameter (LENS_X, LENS_Y, the middle of
    the lid by default) and the camera board is placed from it, connector still
    toward the Pi's CSI end. That moves the camera 12 mm away from the CSI
    connector, so the 38 mm cable has 12 mm furt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
2026-10-16 Cross-compile for the LicheeRV Nano (riscv64gc musl)
    The LicheeRV Nano W (SOPHGO SG2002, C906 RV64GC) joins the Pi Zero W and
    Zero 2 W as a target. The binary builds unchanged as a static musl ELF with
    the toolchain's rust-lld, the same way as the Pi build; nothing has run on
    the board yet.
2026-10-16 Case: a variant for a Zero with the pin header soldered on
    case.py now builds both cases in one run. The header variant
    (body-header.stl, lid-header.stl, 19.8 mm instead of 13.7) raises the Pi
    1.8 mm so the solder tails (taken as 2 mm) clear the floor, and the lid
    4.3 mm so the camera clip over the header clears the 8.5 mm pins by 0.3.
    The lens window moves 0.8 mm toward the USB side so the camera's back
    connector clears the header. The header stays inside the case.
    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
2026-10-17 One rpicam-still at a time, and a hung one is killed
    Two captures started together (a screenshot while capture_debug was still
    running) made the second rpicam-still fail with "pipeline handler in use",
    and the first could then stay stuck retrying "unicam: Failed to start media
    pipeline: -22", holding the camera until the service restarted.
    Every rpicam-still run (captures and --list-cameras) now holds one lock, and
    one still running 60 s past its settle time is killed and reported, freeing
    the camera. Each capture writes its metadata to its own file, so two
    requests no longer share one.
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
